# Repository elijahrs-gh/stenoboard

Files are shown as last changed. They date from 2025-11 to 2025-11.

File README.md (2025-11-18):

# Stenoboard V1
A 28 key stenography keyboard.

**Finished 3D Render:**
Screenshot 2025-11-18 at 10 33 20 AM

## Pictures

**PCB:**
Screenshot 2025-11-11 at 11 15 22 AM

**Schematic:**
Screenshot 2025-11-11 at 11 15 42 AM

**Case:**
Screenshot 2025-11-11 at 11 15 57 AM

## BOM
| Reference | Qty | Value | DNP | Exclude from BOM | Exclude from Board | Footprint | Datasheet |
|---|-----|---|-----|---|---|---|---|
| A1 | 1 | RaspberryPi_Pico | | | | Module:RaspberryPi_Pico_Common_Unspecified | https://datasheets.raspberrypi.com/pico/pico-datasheet.pdf |
| D1, D2 | 2 | SK6812MINI | | | | LED_SMD:LED_SK6812MINI_PLCC4_3.5x3.5mm_P1.75mm | https://cdn-shop.adafruit.com/product-files/2686/SK6812MINI_REV.01-1-2.pdf |
| D3–D30 (28 parts) | 28  | 1N4148 | | | | Diode_THT:D_DO-35_SOD27_P7.62mm_Horizontal | https://assets.nexperia.com/documents/data-sheet/1N4148_1N4448.pdf |
| SW1–SW28 (28 switches) | 28  | SW_Push  | | | | Button_Switch_Keyboard:SW_Cherry_MX_1.00u_PCB | ~ |

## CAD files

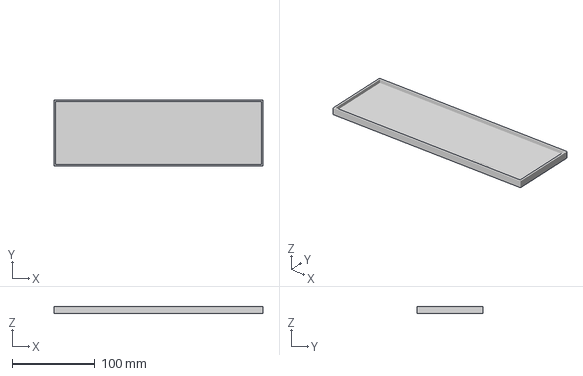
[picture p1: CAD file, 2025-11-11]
CAD/stenoboard.3mf
252.0 x 80.0 x 8.00 mm

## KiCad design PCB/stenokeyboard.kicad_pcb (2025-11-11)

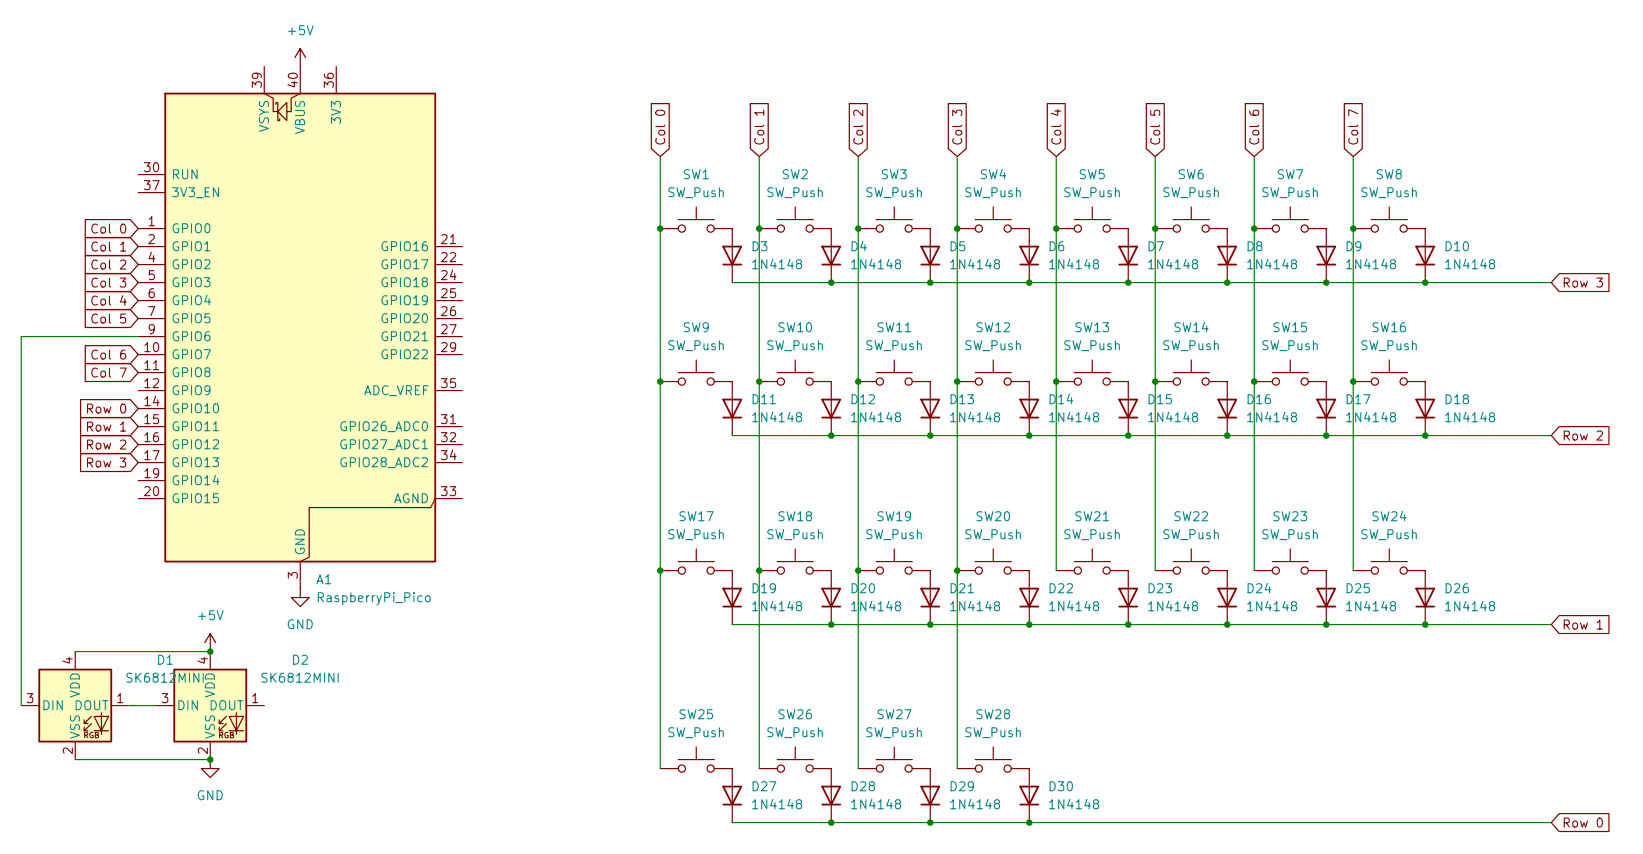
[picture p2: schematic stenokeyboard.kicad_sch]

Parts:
A1: RaspberryPi_Pico; RaspberryPi_Pico_Common_Unspecified
D1, D2: SK6812MINI; LED_SK6812MINI_PLCC4_3.5x3.5mm_P1.75mm
D3, D4, D5, D6, D7, D8, D9, D10, D11, D12, D13, D14, D15, D16, D17, D18, D19, D20, D21, D22, D23, D24, D25, D26, D27, D28, D29, D30: 1N4148; D_DO-35_SOD27_P7.62mm_Horizontal
SW1, SW2, SW3, SW4, SW5, SW6, SW7, SW8, SW9, SW10, SW11, SW12, SW13, SW14, SW15, SW16, SW17, SW18, SW19, SW20, SW21, SW22, SW23, SW24, SW25, SW26, SW27, SW28: SW_Push; SW_Cherry_MX_1.00u_PCB

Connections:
+5V: A1.40 (VBUS), D1.4 (VDD), D2.4 (VDD)
Col 0: A1.1 (GPIO0), SW1.1, SW9.1, SW17.1, SW25.1
Col 1: A1.2 (GPIO1), SW2.1, SW10.1, SW18.1, SW26.1
Col 2: A1.4 (GPIO2), SW3.1, SW11.1, SW19.1, SW27.1
Col 3: A1.5 (GPIO3), SW4.1, SW12.1, SW20.1, SW28.1
Col 4: A1.6 (GPIO4), SW5.1, SW13.1, SW21.1
Col 5: A1.7 (GPIO5), SW6.1, SW14.1, SW22.1
Col 6: A1.10 (GPIO7), SW7.1, SW15.1, SW23.1
Col 7: A1.11 (GPIO8), SW8.1, SW16.1, SW24.1
GND: A1.3 (GND), A1.8 (GND), A1.13 (GND), A1.18 (GND), A1.23 (GND), A1.28 (GND), A1.38 (GND), D1.2 (VSS), D2.2 (VSS)
unnamed: A1.9 (GPIO6), D1.3 (DIN)
unnamed: D1.1 (DOUT), D2.3 (DIN)
unnamed: D3.2 (A), SW1.2
unnamed: D4.2 (A), SW2.2
unnamed: D5.2 (A), SW3.2
unnamed: D6.2 (A), SW4.2
unnamed: D7.2 (A), SW5.2
unnamed: D8.2 (A), SW6.2
unnamed: D9.2 (A), SW7.2
unnamed: D10.2 (A), SW8.2
unnamed: D11.2 (A), SW9.2
unnamed: D12.2 (A), SW10.2
unnamed: D13.2 (A), SW11.2
unnamed: D14.2 (A), SW12.2
unnamed: D15.2 (A), SW13.2
unnamed: D16.2 (A), SW14.2
unnamed: D17.2 (A), SW15.2
unnamed: D18.2 (A), SW16.2
unnamed: D19.2 (A), SW17.2
unnamed: D20.2 (A), SW18.2
unnamed: D21.2 (A), SW19.2
unnamed: D22.2 (A), SW20.2
unnamed: D23.2 (A), SW21.2
unnamed: D24.2 (A), SW22.2
unnamed: D25.2 (A), SW23.2
unnamed: D26.2 (A), SW24.2
unnamed: D27.2 (A), SW25.2
unnamed: D28.2 (A), SW26.2
unnamed: D29.2 (A), SW27.2
unnamed: D30.2 (A), SW28.2
Row 0: A1.14 (GPIO10), D27.1 (K), D28.1 (K), D29.1 (K), D30.1 (K)
Row 1: A1.15 (GPIO11), D19.1 (K), D20.1 (K), D21.1 (K), D22.1 (K), D23.1 (K), D24.1 (K), D25.1 (K), D26.1 (K)
Row 2: A1.16 (GPIO12), D11.1 (K), D12.1 (K), D13.1 (K), D14.1 (K), D15.1 (K), D16.1 (K), D17.1 (K), D18.1 (K)
Row 3: A1.17 (GPIO13), D3.1 (K), D4.1 (K), D5.1 (K), D6.1 (K), D7.1 (K), D8.1 (K), D9.1 (K), D10.1 (K)

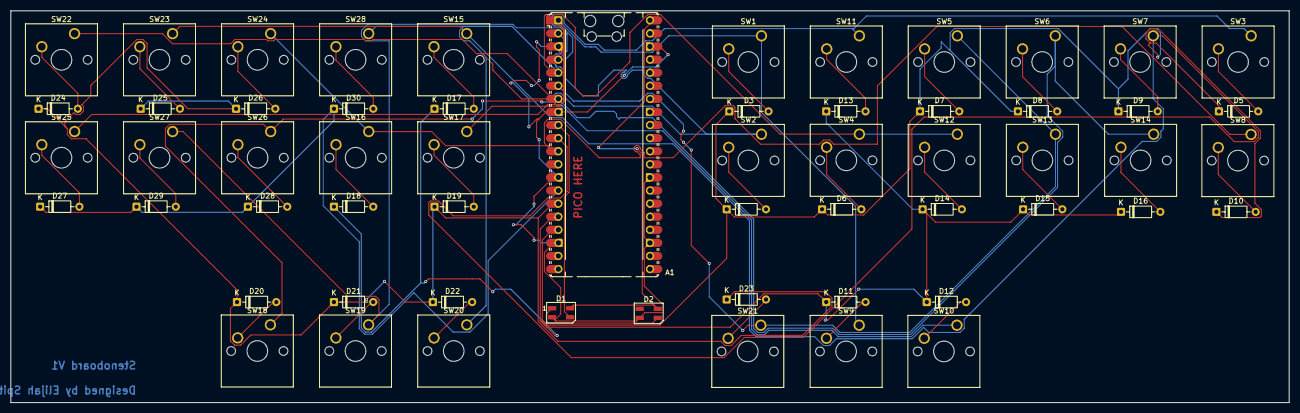
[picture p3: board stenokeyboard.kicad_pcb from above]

Board: 2 copper layers, 248.0 x 76.0 mm, 59 parts (0 on the bottom side), 44 nets.

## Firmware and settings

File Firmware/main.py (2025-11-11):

import board
import neopixel
from kmk.kmk_keyboard import KMKKeyboard
from kmk.keys import KC
from kmk.scanners import DiodeOrientation
from kmk.extensions.steno import Steno

keyboard = KMKKeyboard()
keyboard.extensions.append(Steno())

keyboard.col_pins = (
    board.GP0,  # Col 0
    board.GP1,  # Col 1
    board.GP2,  # Col 2
    board.GP3,  # Col 3
    board.GP4,  # Col 4
    board.GP5,  # Col 5
    board.GP7,  # Col 6
    board.GP8,  # Col 7
)

keyboard.row_pins = (
    board.GP10,  # Row 0
    board.GP11,  # Row 1
    board.GP12,  # Row 2
    board.GP13,  # Row 3
)

keyboard.diode_orientation = DiodeOrientation.COL2ROW

pixels = neopixel.NeoPixel(board.GP6, 2, brightness=0.2, auto_write=False)
pixels.fill((0, 8, 0))
pixels.show()

def after_scan(task):
    r, g, b = pixels[0]
    pixels[0] = (r ^ 1, g, b)
    pixels.show()

keyboard.after_hid_send.append(after_scan)

keyboard.keymap = [
    [
        KC.STN_S1, KC.STN_TL, KC.STN_PL, KC.STN_HL, KC.STN_ST1, KC.STN_FR, KC.STN_PR, KC.STN_LR,
        KC.STN_S2, KC.STN_KL, KC.STN_WL, KC.STN_RL, KC.STN_ST2, KC.STN_RR, KC.STN_BR, KC.STN_GR,
        KC.STN_N1, KC.STN_A,  KC.STN_O,  KC.NO,     KC.NO,      KC.STN_E,  KC.STN_U, KC.STN_N2,
        KC.NO, KC.NO, KC.NO, KC.NO, KC.NO, KC.NO, KC.NO, KC.NO,
    ]
]

if __name__ == '__main__':
    keyboard.go()
